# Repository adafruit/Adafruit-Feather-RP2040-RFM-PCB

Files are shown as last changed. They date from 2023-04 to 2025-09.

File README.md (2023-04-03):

## Adafruit Feather RP2040 RFM PCB

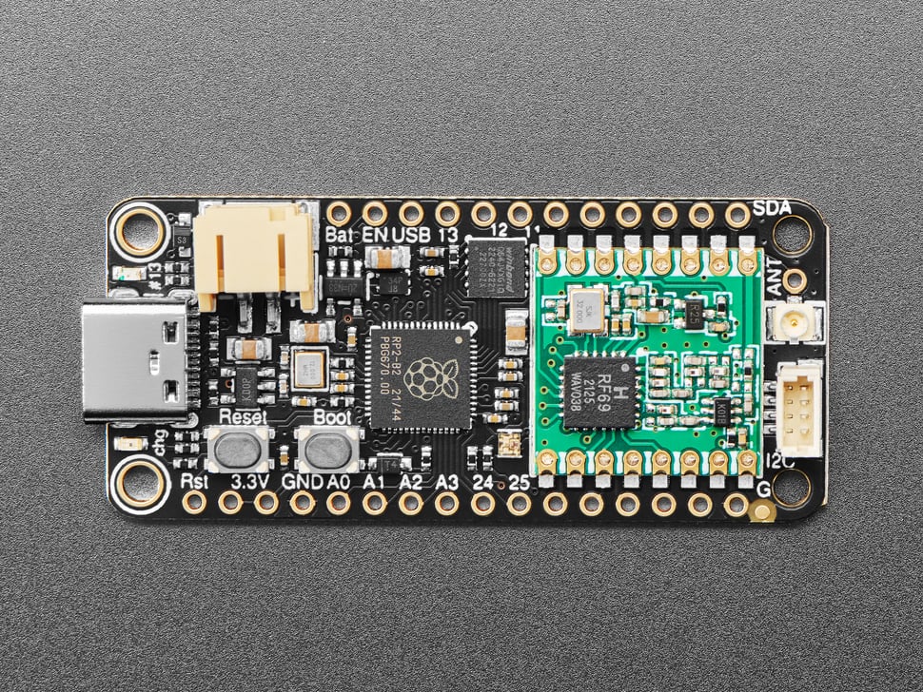
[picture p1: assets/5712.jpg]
<a href="http://www.adafruit.com/products/5712"><br/>
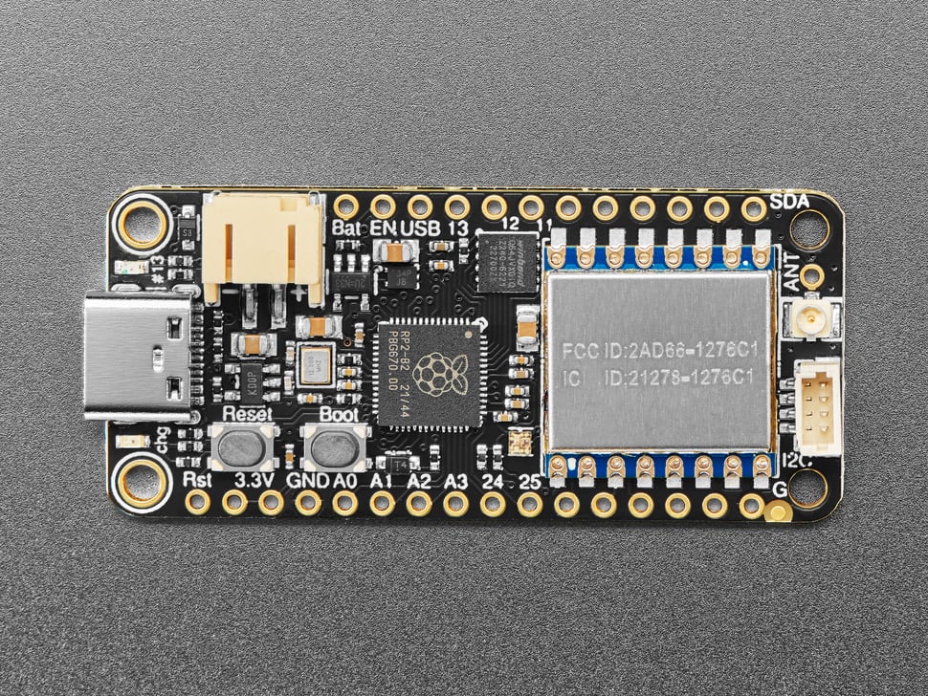
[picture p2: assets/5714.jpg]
<a href="http://www.adafruit.com/products/5714"><br/>
Click here to purchase one from the Adafruit shop</a>

PCB files for the Adafruit Feather RP2040 RFM69 and RFM9x. The board files are identical for both
types of radio modules!

Format is EagleCAD schematic and board layout
* https://www.adafruit.com/product/5712

### Description

This is the Adafruit Feather RP2040 RFM. We call these RadioFruits, our take on a microcontroller with packet radio transceiver with built-in USB and battery charging. It's an Adafruit Feather RP2040 with a radio module cooked in! Great for making wireless networks that are more flexible than Bluetooth LE and without the high power requirements of WiFi.

Feather is the development board specification from Adafruit, and like its namesake, it is thin, light, and lets you fly! We designed Feather to be a new standard for portable microcontroller cores. We have other boards in the Feather family, check'em out here.

It's kinda like we took our RP2040 Feather and an RFM breakout board and glued them together. You get all the pins for use on the Feather, the Lipoly battery support, USB C power / data, onboard NeoPixel, 8MB of FLASH for storing code and files, and then with the 8 unused pins, we wired up all the DIO pins on the RFM module. There's even room left over for a STEMMA QT connector an a uFL connector for connecting larger antennas.

At the Feather's heart is an RP2040 chip, clocked at 133 MHz and at 3.3V logic, the same one used in the Raspberry Pi Pico. This chip has a whopping 8MB of onboard QSPI FLASH and 264K of RAM! This makes it great for making wireless sensor nodes that can send to each other without a lot of software configuration.

To make it easy to use for portable projects, we added a connector for any of our 3.7V Lithium polymer batteries and built-in battery charging. You don't need a battery, it will run just fine straight from the USB Type C connector. But, if you do have a battery, you can take it on the go, then plug in the USB to recharge. The Feather will automatically switch over to USB power when its available.

Here're some handy specs! You get:
* Measures approximately 2.0" x 0.9" x 0.28" (50.8mm x 22.8mm x 7mm) without headers soldered in
* Light as a (large?) feather - approximately 6 grams
* RP2040 32-bit Cortex M0+ dual core running at ~133 MHz @ 3.3V logic and power
* 264 KB RAM
* 8 MB SPI FLASH chip for storing files and CircuitPython/MicroPython code storage. No EEPROM
* Tons of GPIO! 21 x GPIO pins with following capabilities:
* Four 12-bit ADCs (one more than Pico)
* Two I2C, Two SPI, and two UART peripherals, we label one for the 'main' interface in standard Feather locations
* 16 x PWM outputs - for servos, LEDs, etc
* Built-in 200mA+ lipoly charger with charging status indicator LED
* Pin #13 red LED for general purpose blinking
* RGB NeoPixel for full-color indication.
* On-board STEMMA QT connector that lets you quickly connect any Qwiic, STEMMA QT or Grove I2C devices with no soldering!
* Both Reset button and Bootloader select button for quick restarts (no unplugging-replugging to relaunch code)
* USB Type C connector lets you access built-in ROM USB bootloader and serial port debugging
* 3.3V Power/enable pin
* 4 mounting holes
* 12 MHz crystal for perfect timing.
* 3.3V regulator with 500mA peak current output

We squished all the parts on our Feather RP2040 over towards the USB port to make some room on the end. This Feather RFM uses the extra space left over to add an RFM radio module. These radios are not good for transmitting audio or video, but they do work quite well for small data packet transmission when you need more range than 2.4 GHz (BT, BLE, WiFi, ZigBee).

Radio module specifications:

* SX1231 or SX127x LoRa® based module with SPI interface
* +13 to +20 dBm up to 100 mW Power Output Capability (power output selectable in software)
* 50mA (+13 dBm) to 150mA (+20dBm) current draw for transmissions, ~30mA during active radio listening.
* Range of approx. 500 meters to 2Km, depending on which RFM module, as well as obstructions, frequency, antenna and power output
* Create multipoint networks with individual node addresses
* Encrypted packet engine with AES-128
* Packet/LoRa radio with ready-to-go Arduino & CircuitPython libraries
* Uses the license-free ISM bands (ITU "Europe" @ 433MHz and ITU "Americas" @ 900MHz)
* Simple wire antenna can be soldered into a solder pad, there's also a uFL connector that can be used with uFL-to-SMA adapters for attaching bigger antennas.

* Comes fully assembled and tested, we also toss in some headers so you can solder it in and plug into a solderless breadboard. You will need to cut and solder on a small piece of wire (any solid or stranded core is fine) in order to create your antenna. or use a uFL connector and an appropriate SMA antenna. Lipoly battery and USB cable are not included, but we do have lots of options in the shop if you'd like!

### License

Adafruit invests time and resources providing this open source design, please support Adafruit and open-source hardware by purchasing products from [Adafruit](https://www.adafruit.com)!

Designed by Limor Fried/Ladyada for Adafruit Industries.

Creative Commons Attribution/Share-Alike, all text above must be included in any redistribution. 
See license.txt for additional details.

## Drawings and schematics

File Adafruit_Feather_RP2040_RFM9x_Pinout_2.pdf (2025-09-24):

# Adafruit Feather RP2040 RFM9x

# https://www.adafruit.com/product/5714

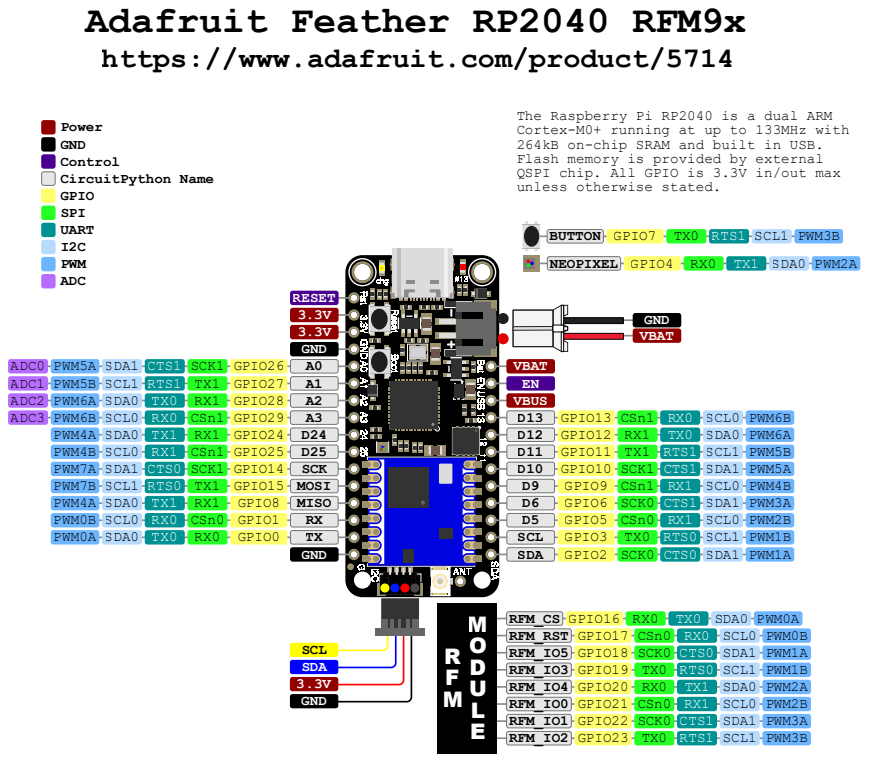
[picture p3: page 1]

The Raspberry Pi RP2040 is a dual ARM
Cortex-M0+ running at up to 133MHz with
264kB on-chip SRAM and built in USB.
Flash memory is provided by external
QSPI chip. All GPIO is 3.3V in/out max
unless otherwise stated.

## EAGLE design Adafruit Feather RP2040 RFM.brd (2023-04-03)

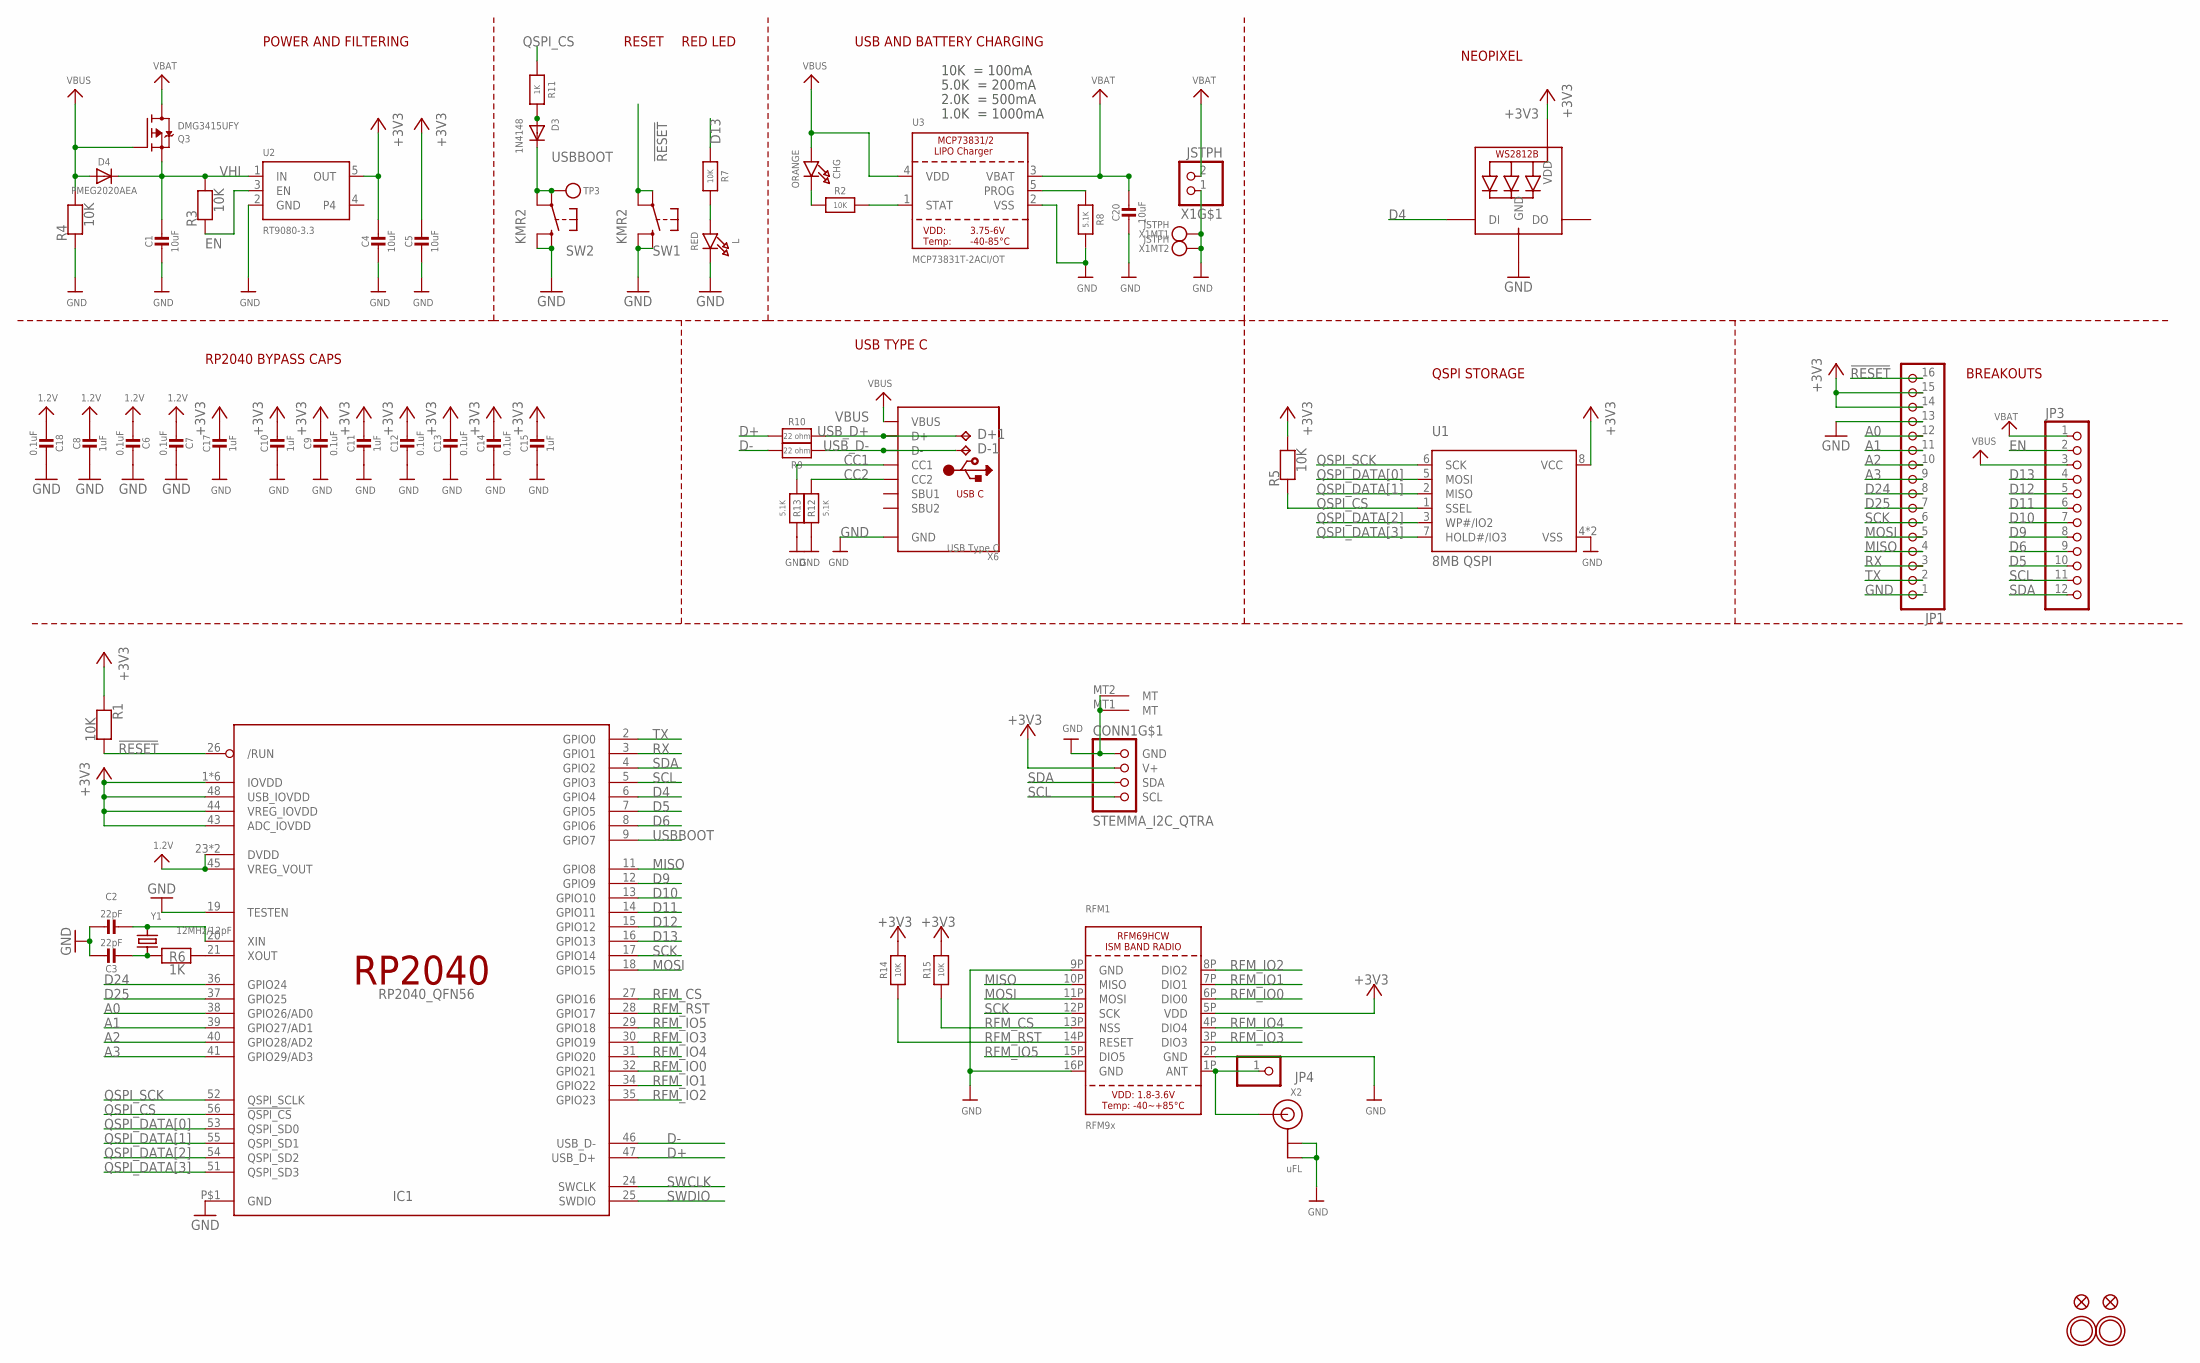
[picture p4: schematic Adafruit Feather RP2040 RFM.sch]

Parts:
C1, C4, C5, C20: 10uF; 0805-NO
C2, C3: 22pF; _0402NO
C6, C7, C9, C12, C13, C14, C18: 0.1uF; _0402NO
C8, C10, C11, C15, C17: 1uF; _0402NO
CHG: ORANGE; CHIPLED_0603_NOOUTLINE
CONN1: STEMMA_I2C_QTRA; JST_SH4_RA
D3: 1N4148; SOD-323F
D4: PMEG2020AEA; SOD-323F
D+1: TPB1,27; B1,27
D-1: TPB1,27; B1,27
IC1: RP2040_QFN56; QFN56_7MM_REDUCEDEPAD
JP1: HEADER-1X16ROUND; 1X16_ROUND
JP3: HEADER-1X12; 1X12_ROUND
JP4: HEADER-1X1ROUND; 1X01_ROUND
L: RED; CHIPLED_0603_NOOUTLINE
LED1: WS2812B_SK6805_1515; SK6805_1515
Q3: DMG3415UFY; DFN2015-3
R1, R2, R3, R4, R5, R7, R14, R15: 10K; _0402NO
R6, R11: 1K; _0402NO
R8, R12, R13: 5.1K; _0402NO
R9, R10: 22 ohm; _0402NO
RFM1: RFM9x; RFMHCW_SMT
SW1, SW2: KMR2; BTN_RKB2_4.6X2.8
TP3: TESTPOINTROUND1.5MMNO; TESTPOINT_ROUND_1.5MM_NO
U1: 8MB QSPI; USON8_4X4
U2: RT9080-3.3; SOT23-5; JLC_ROTATION 0
U3: MCP73831T-2ACI/OT; SOT23-5
U$31, U$32: MOUNTINGHOLE2.5; MOUNTINGHOLE_2.5_PLATED
U$34, U$35: FIDUCIAL_1MM
X1: JSTPH; JSTPH2_BATT
X2: uFL; U.FL
X6: USB Type C; USB_C_CUSB31-CFM2AX-01-X
Y1: 12MHz/12pF; CRYSTAL_2.5X2

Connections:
1.2V: C6.2, C7.2, C8.1, C18.2, IC1.23 (DVDD), IC1.45 (VREG_VOUT), IC1.50 (DVDD)
!RESET: IC1.26 (/RUN), JP1.16, R1.2, SW1.A, SW1.A' (P1)
+3V3: C4.1, C5.1, C9.1, C10.1, C11.1, C12.1, C13.1, C14.1, C15.1, C17.1, CONN1.2 (V+), IC1.1 (IOVDD), IC1.10 (IOVDD), IC1.22 (IOVDD), IC1.33 (IOVDD), IC1.42 (IOVDD), IC1.43 (ADC_IOVDD), IC1.44 (VREG_IOVDD), IC1.48 (USB_IOVDD), IC1.49 (IOVDD), JP1.14, JP1.15, LED1.2 (VDD), R1.1, R5.2, R14.2, R15.2, RFM1.5P (VDD), U1.8 (VCC), U2.5 (OUT)
A0: IC1.38 (GPIO26/AD0), JP1.12
A1: IC1.39 (GPIO27/AD1), JP1.11
A2: IC1.40 (GPIO28/AD2), JP1.10
A3: IC1.41 (GPIO29/AD3), JP1.9
CC1: R13.2, X6.A5 (CC1)
CC2: R12.2, X6.B5 (CC2)
D4: IC1.6 (GPIO4), LED1.1 (DI)
D5: IC1.7 (GPIO5), JP3.10
D6: IC1.8 (GPIO6), JP3.9
D9: IC1.12 (GPIO9), JP3.8
D10: IC1.13 (GPIO10), JP3.7
D11: IC1.14 (GPIO11), JP3.6
D12: IC1.15 (GPIO12), JP3.5
D13: IC1.16 (GPIO13), JP3.4, R7.1
D24: IC1.36 (GPIO24), JP1.8
D25: IC1.37 (GPIO25), JP1.7
D+: IC1.47 (USB_D+), R10.2
D-: IC1.46 (USB_D-), R9.2
EN: JP3.2, R3.1, U2.3 (EN)
GND: C1.2, C2.1, C3.1, C4.2, C5.2, C6.1, C7.1, C8.2, C9.2, C10.2, C11.2, C12.2, C13.2, C14.2, C15.2, C17.2, C18.1, C20.2, CONN1.1 (GND), CONN1.MT1 (MT), CONN1.MT2 (MT), IC1.19 (TESTEN), IC1.P$1 (GND), JP1.1, JP1.13, L.C, LED1.4 (GND), R4.1, R8.2, R12.1, R13.1, RFM1.2P (GND), RFM1.9P (GND), RFM1.16P (GND), SW1.B (S), SW1.B' (S1), SW2.B (S), SW2.B' (S1), U1.4 (VSS), U1.PAD (VSS), U2.2 (GND), U3.2 (VSS), X1.1, X1.NC1, X1.NC2, X2.1 (GND), X2.2 (GND), X6.A1B12 (GND), X6.B1A12 (GND)
MISO: IC1.11 (GPIO8), JP1.4, RFM1.10P (MISO)
MOSI: IC1.18 (GPIO15), JP1.5, RFM1.11P (MOSI)
unnamed: CHG.C, R2.1
unnamed: L.A, R7.2
unnamed: R2.2, U3.1 (STAT)
unnamed: R8.1, U3.5 (PROG)
unnamed: C2.2, IC1.20 (XIN), Y1.3 (2)
unnamed: C3.2, R6.1, Y1.1
unnamed: IC1.21 (XOUT), R6.2
unnamed: D3.A, R11.2
QSPI_CS: IC1.56 (!QSPI_CS), R5.1, R11.1, U1.1 (SSEL)
QSPI_DATA[0]: IC1.53 (QSPI_SD0), U1.5 (MOSI)
QSPI_DATA[1]: IC1.55 (QSPI_SD1), U1.2 (MISO)
QSPI_DATA[2]: IC1.54 (QSPI_SD2), U1.3 (WP#/IO2)
QSPI_DATA[3]: IC1.51 (QSPI_SD3), U1.7 (HOLD#/IO3)
QSPI_SCK: IC1.52 (QSPI_SCLK), U1.6 (SCK)
RFM_CS: IC1.27 (GPIO16), R15.1, RFM1.13P (NSS)
RFM_IO0: IC1.32 (GPIO21), RFM1.6P (DIO0)
RFM_IO1: IC1.34 (GPIO22), RFM1.7P (DIO1)
RFM_IO2: IC1.35 (GPIO23), RFM1.8P (DIO2)
RFM_IO3: IC1.30 (GPIO19), RFM1.3P (DIO3)
RFM_IO4: IC1.31 (GPIO20), RFM1.4P (DIO4)
RFM_IO5: IC1.29 (GPIO18), RFM1.15P (DIO5)
RFM_RST: IC1.28 (GPIO17), R14.1, RFM1.14P (RESET)
RFOUT: JP4.1, RFM1.1P (ANT), X2.3 (SIGNAL)
RX: IC1.3 (GPIO1), JP1.3
SCK: IC1.17 (GPIO14), JP1.6, RFM1.12P (SCK)
SCL: CONN1.4 (SCL), IC1.5 (GPIO3), JP3.11
SDA: CONN1.3 (SDA), IC1.4 (GPIO2), JP3.12
SWCLK: IC1.24 (SWCLK)
SWDIO: IC1.25 (SWDIO)
TX: IC1.2 (GPIO0), JP1.2
USBBOOT: D3.C, IC1.9 (GPIO7), SW2.A, SW2.A' (P1), TP3.P$1
USB_D+: D+1.TP, R10.1, X6.A6 (D+), X6.B6 (D+)
USB_D-: D-1.TP, R9.1, X6.A7 (D-), X6.B7 (D-)
VBAT: C20.1, JP3.1, Q3.3 (D), U3.3 (VBAT), X1.2
VBUS: CHG.A, D4.A, JP3.3, Q3.1 (G), R4.2, U3.4 (VDD), X6.A4B9 (VBUS), X6.B4A9 (VBUS)
VHI: C1.1, D4.C, Q3.2 (S), R3.2, U2.1 (IN)

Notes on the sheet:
POWER AND FILTERING
RESET
10K = 100mA
5.0K = 200mA
2.0K = 500mA
1.0K = 1000mA
USB AND BATTERY CHARGING
BREAKOUTS
RED LED
RP2040 BYPASS CAPS
USB TYPE C
QSPI STORAGE
NEOPIXEL

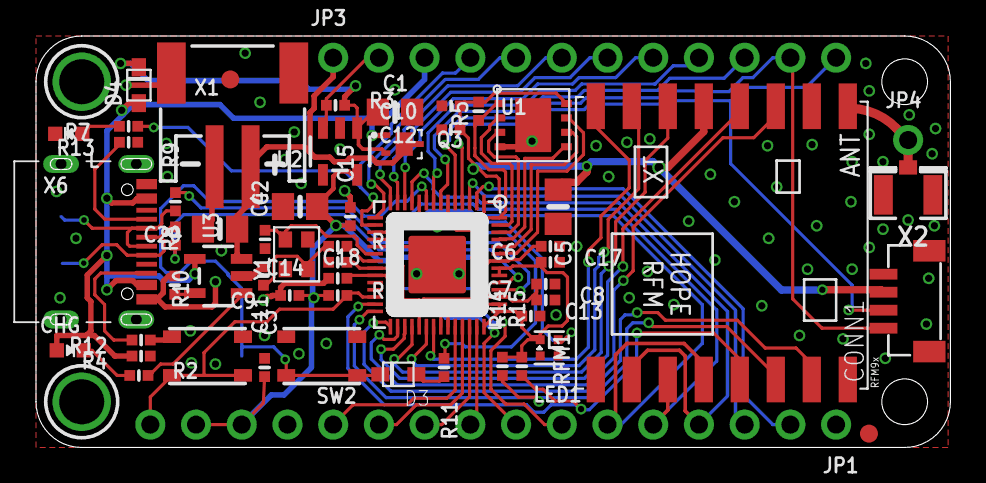
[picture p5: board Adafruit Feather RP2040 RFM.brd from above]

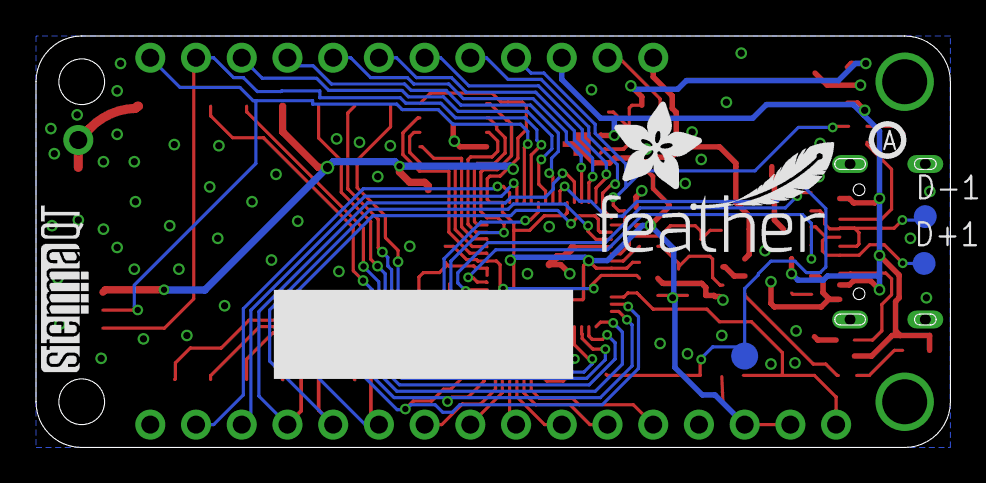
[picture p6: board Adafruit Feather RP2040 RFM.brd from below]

Board: 2 copper layers, 50.8 x 22.9 mm, 120 parts (39 on the bottom side), 59 nets.

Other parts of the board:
PLABEL0: PLABEL0
PLABEL1: PLABEL1
PLABEL2: PLABEL2
PLABEL3: PLABEL3
PLABEL4: PLABEL4
PLABEL5: PLABEL5
PLABEL6: PLABEL6
PLABEL7: PLABEL7
PLABEL8: PLABEL8
PLABEL9: PLABEL9
PLABEL10: PLABEL10
PLABEL11: PLABEL11
PLABEL12: PLABEL12
PLABEL13: PLABEL13
PLABEL14: PLABEL14
PLABEL15: PLABEL15
PLABEL16: PLABEL16
PLABEL17: PLABEL17
PLABEL18: PLABEL18
PLABEL19: PLABEL19
PLABEL20: PLABEL20
PLABEL21: PLABEL21
PLABEL22: PLABEL22
PLABEL23: PLABEL23
PLABEL24, PLABEL54: PLABEL24
PLABEL25: PLABEL25
PLABEL26: PLABEL26
PLABEL27: PLABEL27
PLABEL28: PLABEL28
PLABEL29: PLABEL29
PLABEL30: PLABEL30
PLABEL31: PLABEL31
PLABEL32: PLABEL32
PLABEL33: PLABEL33
PLABEL34: PLABEL34
PLABEL35: PLABEL35
PLABEL36: PLABEL36
PLABEL37: PLABEL37
PLABEL38: PLABEL38
PLABEL39: PLABEL39
PLABEL40: PLABEL40
PLABEL41: PLABEL41
PLABEL42: PLABEL42
PLABEL43: PLABEL43
PLABEL44: PLABEL44
PLABEL45: PLABEL45
PLABEL46: PLABEL46
PLABEL47: PLABEL47
PLABEL48: PLABEL48
PLABEL49: PLABEL49
PLABEL51: PLABEL51
PLABEL52: PLABEL52
PLABEL53: PLABEL53
PLABEL540: PLABEL540
U$13: PCBFEAT-REV-040
U$45: ADAFRUIT_5MM
U$46: STEMMAQT
U$47: FEATHERLOGO_SMALL

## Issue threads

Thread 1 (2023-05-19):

DMG3415UFY might be flipped? Possible better battery performance

maqifrnswa, 2023-05-19:
From:
https://cdn-learn.adafruit.com/assets/assets/000/120/101/original/adafruit_products_FRPRFM69_sch.png

The p-channel MOSFET (DMG3415) is used as a high side switch to connect the battery to the 3.3 regulator when the USB 5V is not present. However, the MOSFET appears to be in "backwards" - the source should connect to the battery, the drain to Vin on the regulator (in the linked schematic it is switched). I don't have Eagle, so I can't confirm that it is corrected in production. If it is, then the documentation can be corrected, otherwise it's possible to improve battery life/performance by switching the source and drain.

The "incorrect" high side switch still works since the body diode of the MOSFET will still allow current to flow from the battery to the regulator when the USB bus is not present. However, as it is currently designed, using the body diode of the transistor incurs an additional (unnecessary) voltage drop. If the MOSFET is "corrected" to be a high side switch, the MOSFET will just show Rds(on) (i.e., <1 Ohm) to the battery, allowing the system to operate at lower battery levels than is currently possible (as appears to have been the original design intent).

maqifrnswa, 2023-05-20:
Ah, sorry, it still works as is - it's clever in that the body diode allows current to flow, then the source goes positive, gate goes to ground, then the channel forms. Sorry for the noise!

Closed 2023-05-21.

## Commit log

2023-04-03 Add board files.
    [Adafruit Feather RP2040 RFM.brd, Adafruit Feather RP2040 RFM.sch]
2025-09-24 Add revised prettypins
    Fixes battery JST view

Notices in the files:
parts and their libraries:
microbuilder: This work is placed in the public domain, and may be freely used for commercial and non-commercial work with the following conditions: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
